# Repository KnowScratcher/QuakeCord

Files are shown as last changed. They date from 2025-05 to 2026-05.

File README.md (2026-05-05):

> [!WARNING]
> The server part will be in a different repo, the code here is outdated. See [QuakeCord-server](https://github.com/KnowScratcher/QuakeCord-server).

# QuakeCord
<p align="center">
Whenever an earthquake strikes, you should know what's going on.
</p>

<div align="center">
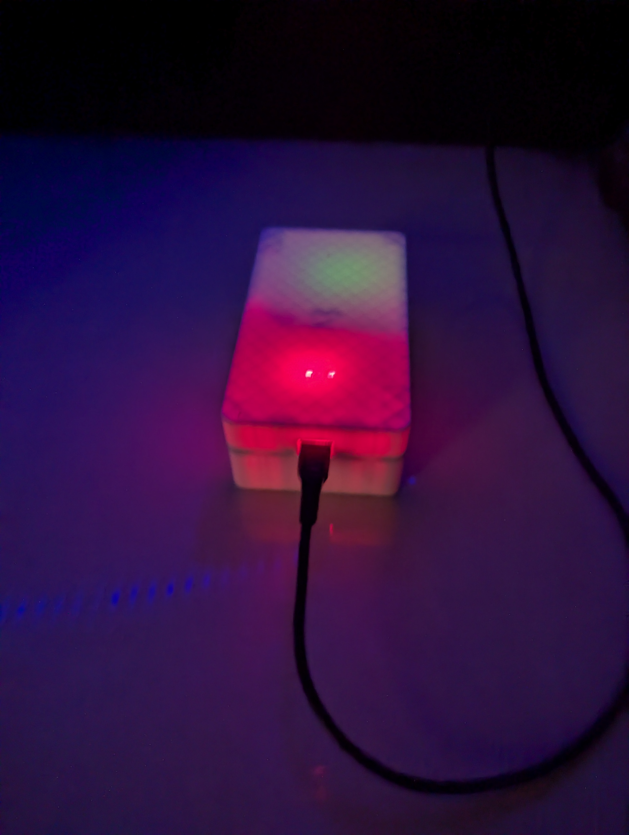
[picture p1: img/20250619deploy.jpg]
    <br>
    certificate
</div>

# BOM
Because I live in Taiwan, so I'll add a TWD column.

| Item | Amount | Price(USD) | Total(USD) | Total(TWD) |
| --- | --- | --- | --- | --- |
| ESP32 dev module | 1 | 5.34 | 5.34 | 160 |
| MPU6050 (soldered) | 1 | 4.33 | 4.33 | 130 |
| Case (3D print) | 1 | 0.91 | 0.91 | 27 |
| Jump wire (pin - socket)  | 5 | 0.19 | 0.19 | 6 |
| Breadboard mini (45x35mm) | 1 | 0.17 | 0.17 | 5 |
| Total | | | 10.75 | 328 |

> [!NOTE] 
> - If you'd like to find a case for the project, go ahead.
> - A 3D printed case will be a cheaper option. (Assuming PLA costs $13.4/KG)

# Journal
The journal is in [JOURNAL.md](JOURNAL.md)

A brief summery of the journal:

## How it all started
I've been wanting to make something useful and about earthquake since I lived in a place with lots of earthquake. Just this simple reason.

## What will it do?
- detect earthquake
- record the acceleration data for further research
- send notification to discord
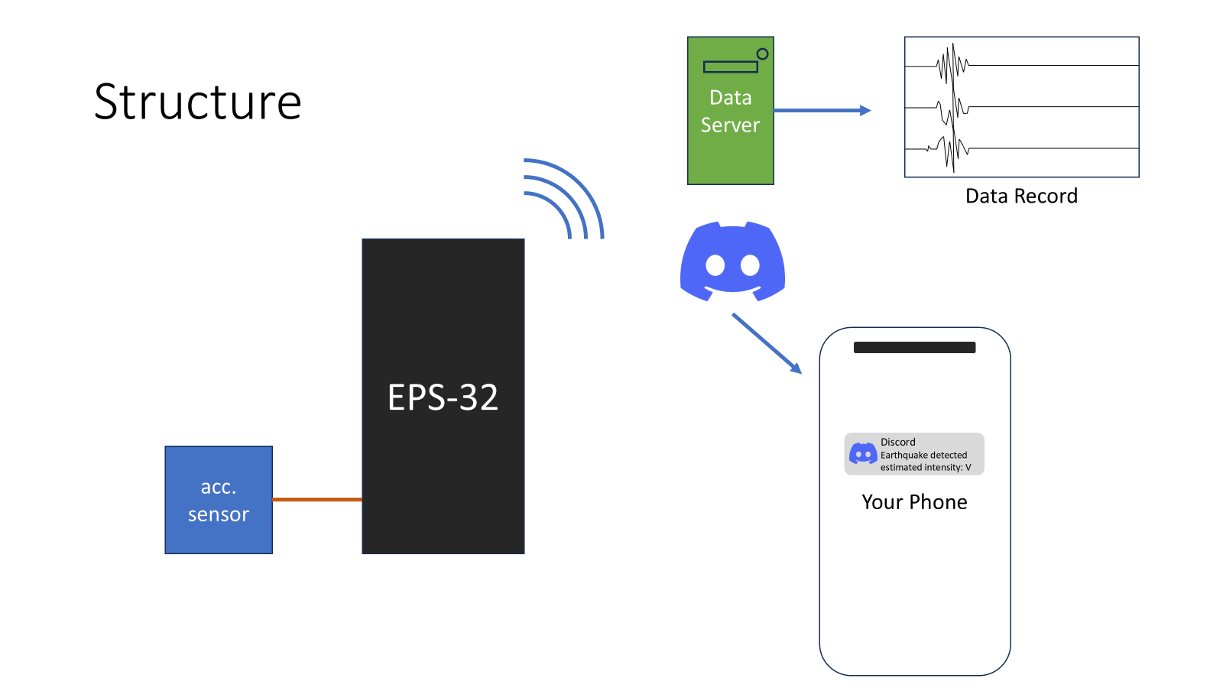
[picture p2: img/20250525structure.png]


# How to make one
1. Head over to [src > print](https://github.com/KnowScratcher/QuakeCord/tree/main/src/print) and download the file you need.

   `QuakeCord_case.3mf`: the whole case including base and cap. (if you choose this, you don't have to download the others.)
   
   `QuakeCord_case_case.3mf`: the base of the case.
   
   `QuakeCord_case_cap.3mf`: the cap of the case.

   Also stl file is provided.

   `QuakeCord_case.stl`: the whole case including base and cap. (if you choose this, you don't have to download the others.)
   
   `QuakeCord_case_case.stl`: the base of the case.
   
   `QuakeCord_case_cap.stl`: the cap of the case.
   
2. Assemble the parts as follows:
   Detail in [wiki](https://github.com/KnowScratcher/QuakeCord/wiki).
   1. glue or foam tape the breadboard onto the case. If 3d printed, there should be an area marked the same size as the breadboard.
   2. plug your MPU6050 onto the breadboard. Note that the pins should align vertically, that is, along the direction which has more holes.
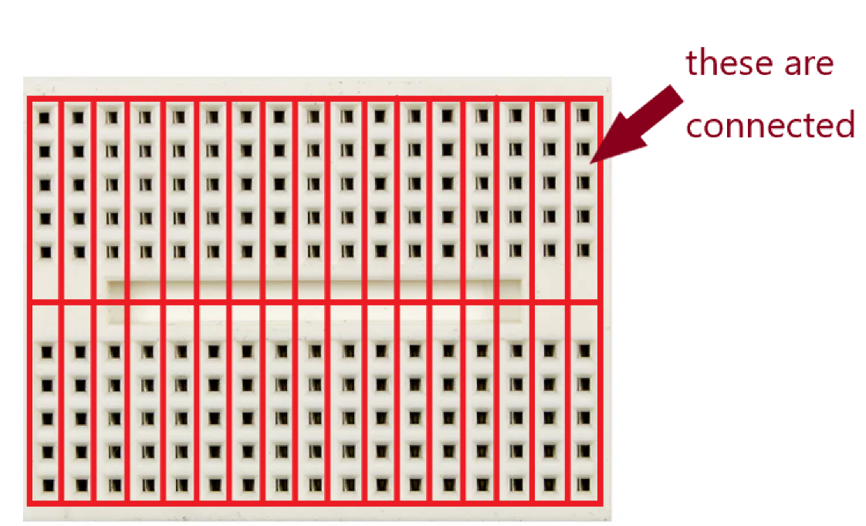
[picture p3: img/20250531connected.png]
what is connected on a breadboard
      
      
      (breadboard image from [arduino store](https://store.arduino.cc/products/mini-breadboard-white))
      
   3. connect the jump wires from ESP32 to the breadboard as follows:
      | ESP32 pin | MPU6050 pin (breadboard) |
      | --------- | ------------------------ |
      | 3v3       | VCC                      |
      | GND       | GND                      |
      | D22       | SCL                      |
      | D21       | SDA                      |
      | D15*      | INT*                     |
      
> [!NOTE]
> An unknown error might appear when you connect the `INT` to the ESP32.
>
> If your QuakeCord suddenly stops working about 30 minutes after you plug in, remove the connection of this pin.
   5. find the script at [not available](about:blank) and edit the setting. (Detail in [wiki](https://github.com/KnowScratcher/QuakeCord/wiki).)
   6. upload the script to your ESP32.
   7. Plug the device somewhere you won't be often and you're good!!!
  
# Software
CAD: PowerPoint, FreeCAD

Programming: VS code, Arduino IDE

Image editing: Paint 3D

# Licensing

This project comprises both hardware designs and software components, each licensed separately to ensure clarity and appropriate reciprocity.

## Long story short
certificate

## Hardware Designs (3D Models, Wiring Diagrams, etc.)

All hardware design files, including but not limited to 3D models, PCB layouts, and schematic diagrams, excluding the ESP32 board, are licensed under the **CERN Open Hardware Licence Version 2 - Strongly Reciprocal (CERN-OHL-S-2.0)**.
You can find the full text of this license in [LICENSE_HARDWARE](LICENSE_HARDWARE).

## Software (Data Server, ESP32 Firmware, etc.)

All software components, including but not limited to the data server application and ESP32 firmware, are licensed under the **GNU Affero General Public License Version 3.0 or later (AGPL-3.0-or-later)**.
You can find the full text of this license in [LICENSE_SOFTWARE](LICENSE_SOFTWARE).

## Documentation

All documentations, including but not limited to the README.md and wiki pages, are licensed under the **CC-BY-SA-4.0**.
You can find the full text of this license in [LICENSE_DOCUMENTATION](LICENSE_DOCUMENTATION)

# Contribute
## Files
### Step Files
step files are available at [src > step](https://github.com/KnowScratcher/QuakeCord/tree/main/src/step)

`QuakeCord_case.step`: All parts together.

`QuakeCord_case_case.step`: only the base.

`QuakeCord_case_cap.step`: only the cap.

Please update all three CADs to your design.
### FreeCAD File
find the `.FCStd` at [src](https://github.com/KnowScratcher/QuakeCord/tree/main/src)

`QuakeCord.FCStd`: the model.

`QuakeCord_case.FCStd`: the actual case. (both base and cap)

## PR
Please describe what exactly you have changed, I will review the PRs once in a while, be patient!

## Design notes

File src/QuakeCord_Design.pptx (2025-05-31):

## QuakeCord Design

The design file

## Structure

Data Server

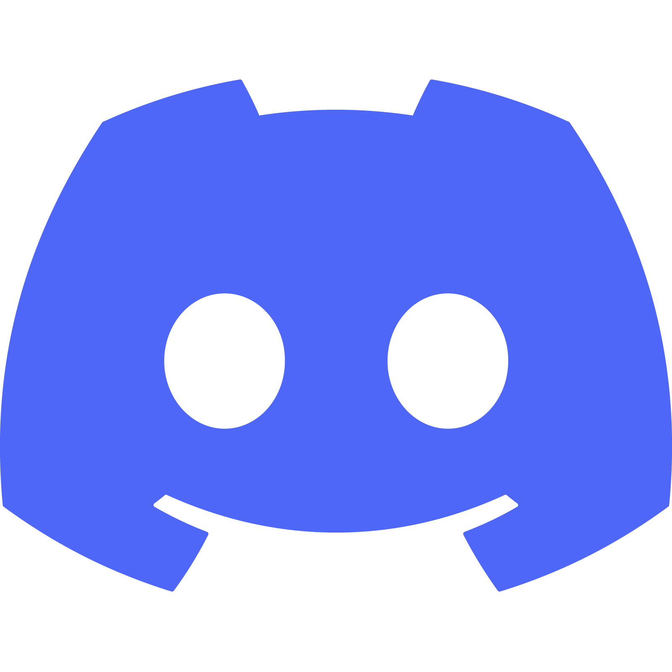
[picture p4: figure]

Data Record

此相片 (http://funclubfrp.wikidot.com/faq) (作者: 未知的作者) 已透過 CC BY-SA (https://creativecommons.org/licenses/by-sa/3.0/) 授權

此相片 (http://funclubfrp.wikidot.com/faq) (作者: 未知的作者) 已透過 CC BY-SA (https://creativecommons.org/licenses/by-sa/3.0/) 授權

EPS-32

Your Phone

Discord

Earthquake detected
estimated intensity: V

acc. sensor

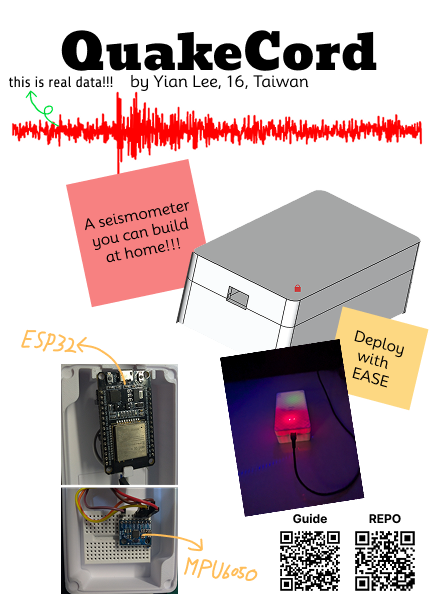
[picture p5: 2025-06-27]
img/quakecord.png

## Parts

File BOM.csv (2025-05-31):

Item | Amount | Price(USD) | Total(USD)
ESP32 dev module | 1 | 5.34 | 5.34
MPU6050 (soldered) | 1 | 10.02 | 10.02
Case (3D print) | 1 | 0.91 | 0.91
Jump wire (pin - socket) | 5 | 0.19 | 0.19
Breadboard mini (45x35mm) | 1 | 0.17 | 0.17
Total |  |  | 16.63

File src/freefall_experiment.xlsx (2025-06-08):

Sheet: raw
8154
7945
7967
7483
8041
8037
7858
8353
8133
7549
7993
7870
7804
7990
7921
7932
8069
8122
8219
8179
8098
7945
8196
8182
8303
8180
8079
8143
8109
8004

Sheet: Plot
id | value | y | id | Average | id | y
experiment | 8154 | 0.5 |  |  |  | 0
experiment | 7945 | 0.5 | experiment | 8028.6 | experiment | 0.5
experiment | 7967 | 0.5 | 0 |  |  | 1
experiment | 7483 | 0.5
experiment | 8041 | 0.5
experiment | 8037 | 0.5
experiment | 7858 | 0.5
experiment | 8353 | 0.5
experiment | 8133 | 0.5
experiment | 7549 | 0.5
experiment | 7993 | 0.5
experiment | 7870 | 0.5
experiment | 7804 | 0.5
experiment | 7990 | 0.5
experiment | 7921 | 0.5
experiment | 7932 | 0.5
experiment | 8069 | 0.5
experiment | 8122 | 0.5
experiment | 8219 | 0.5
experiment | 8179 | 0.5
experiment | 8098 | 0.5
experiment | 7945 | 0.5
experiment | 8196 | 0.5
experiment | 8182 | 0.5
experiment | 8303 | 0.5
experiment | 8180 | 0.5
experiment | 8079 | 0.5
experiment | 8143 | 0.5
experiment | 8109 | 0.5
experiment | 8004 | 0.5
Source: Northwind Traders.

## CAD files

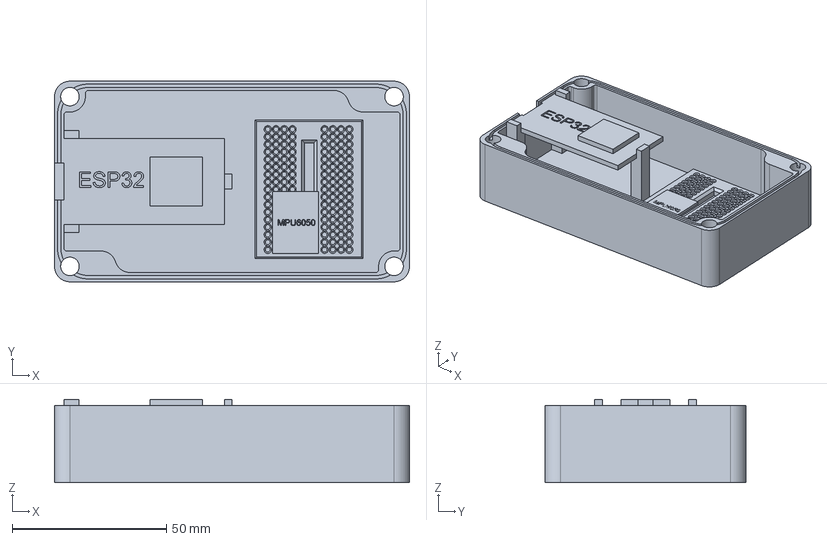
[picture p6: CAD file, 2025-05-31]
src/QuakeCord.FCStd
115.0 x 65.0 x 27.0 mm

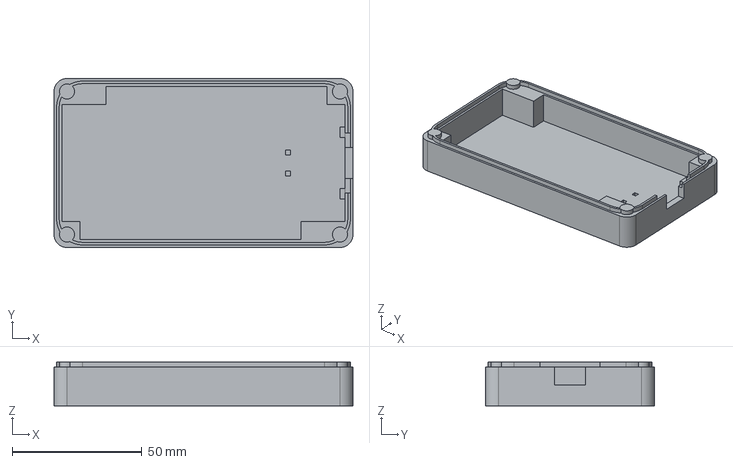
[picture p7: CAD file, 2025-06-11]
src/step/QuakeCord_case-cap.step
115.0 x 65.0 x 16.9 mm

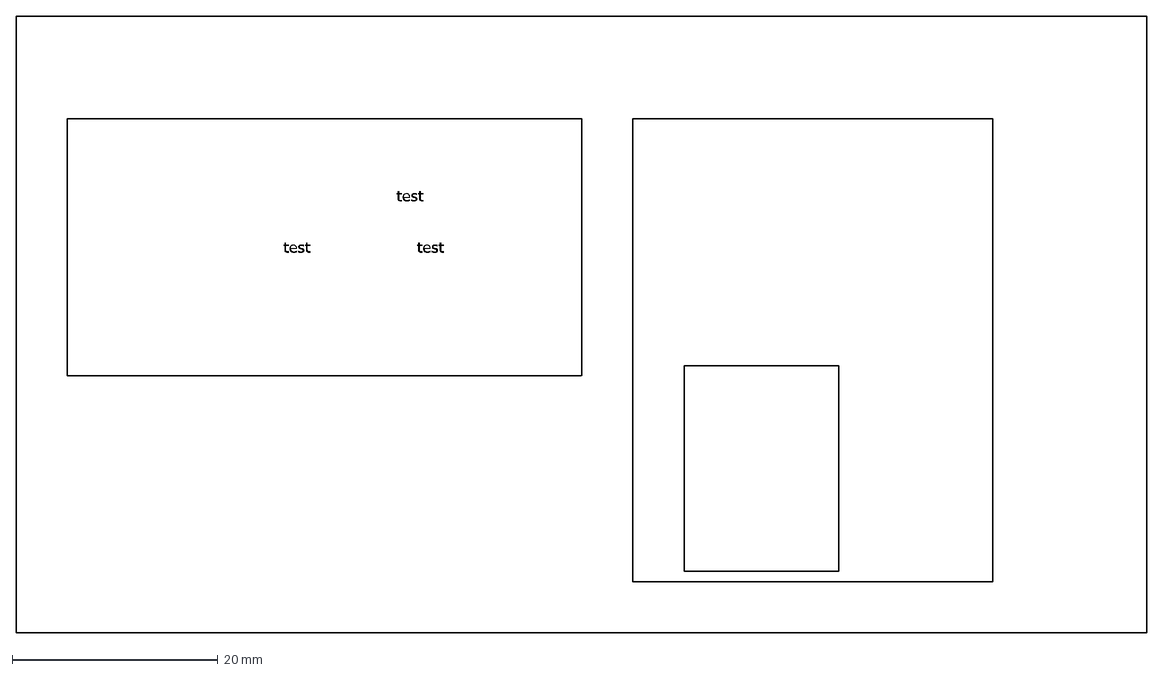
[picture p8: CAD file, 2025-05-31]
src/QuakeCord_Design.dxf
test

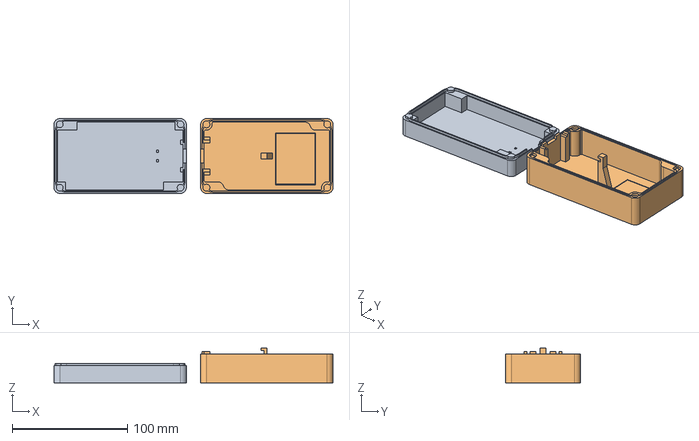
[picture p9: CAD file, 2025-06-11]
src/step/QuakeCord_case.step
242.5 x 65.0 x 30.0 mm
cap
case

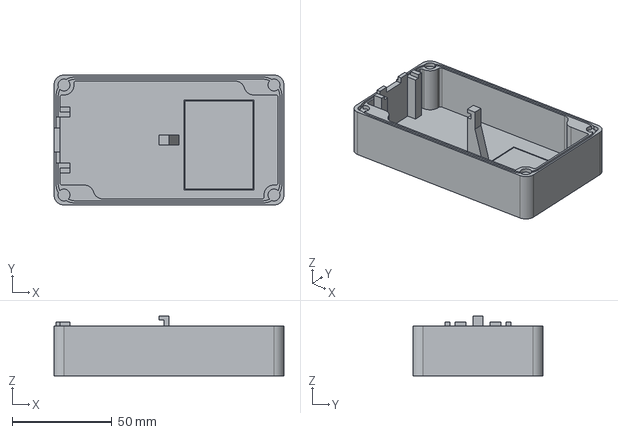
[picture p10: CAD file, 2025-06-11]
src/step/QuakeCord_case-case.step
115.0 x 65.0 x 30.0 mm

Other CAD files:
src/QuakeCord_case.FCStd
src/print/QuakeCord_case-cap.3mf
src/print/QuakeCord_case-cap.stl
src/print/QuakeCord_case-case.3mf
src/print/QuakeCord_case-case.stl
src/print/QuakeCord_case.3mf
src/print/QuakeCord_case.stl

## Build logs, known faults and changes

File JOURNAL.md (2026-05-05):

---
title: "QuakeCord"
author: "Know Scratcher"
description: "An earthquake sensor that connects with discord."
created_at: "2025-05-25"
---

# May 25th: Research and Design + Build a Prototype.

I finally decided to start this project. I've been wanting to make something useful and about earthquake since I lived in a place with lots of earthquake.

The function I planned to have are:
- detect earthquake
- record the acceleration data for further research
- send notification to discord

Here's a quick picture explaining this:

structure

So the things I would need:
- EPS32 (controlling the sensor)
- An accelerometer (of course, for obtaining data)
- A case (for dust protection)
- A data server (for collecting data)

I'll use an ESP-32 dev module to control the hardware because I'm more familiar with it.

Next, I'll need an acceleration sensor. I ask Gemini for suggestion on the sensors, but it seemed like ADXL345 and MPU6050, which I already have, are the most sensitive sensor I can find.

So I read through the data sheet of the [ADXL345](https://www.analog.com/media/en/technical-documentation/data-sheets/adxl345.pdf) and [MPU6050](https://invensense.tdk.com/wp-content/uploads/2015/02/MPU-6000-Datasheet1.pdf).

After all, I decide to use MPU6050 because its extensibility. It has an accelerometer and a gyroscope, which might make it more possible for something more complicated than only an accelerometer.

I use a breadboard to hold my sensor, which it flat enough at the bottom to make the sensor stable, and also I glued a little piece of plastic that somehow just fit the height of the sensor to hold the sensor's other end. 

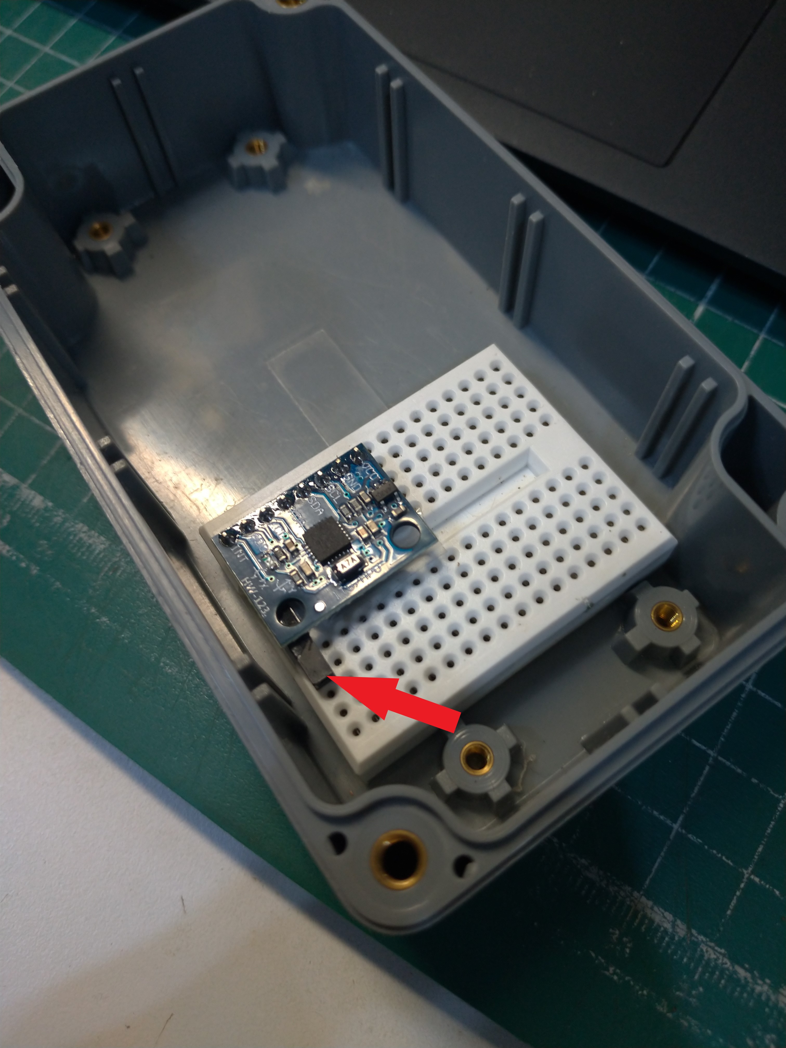
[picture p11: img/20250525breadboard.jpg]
breadboard


Then, I found a library for MPU6050 and spend about one hour trying to understand the example program.

**Total time spent: 4h**

# May 31th: Draw design with FreeCAD.

Basically what I did today is draw the case for the controller and sensor.

I use an existing box as a reference and slightly change the design a little bit to fit.

I got a little pissed when freeCAD not responding every time I was finishing a step.

Because I'm the first time using this software, so I feel a little hard to control everything, but after all the pissing and agony, I finally got something that can be showed.

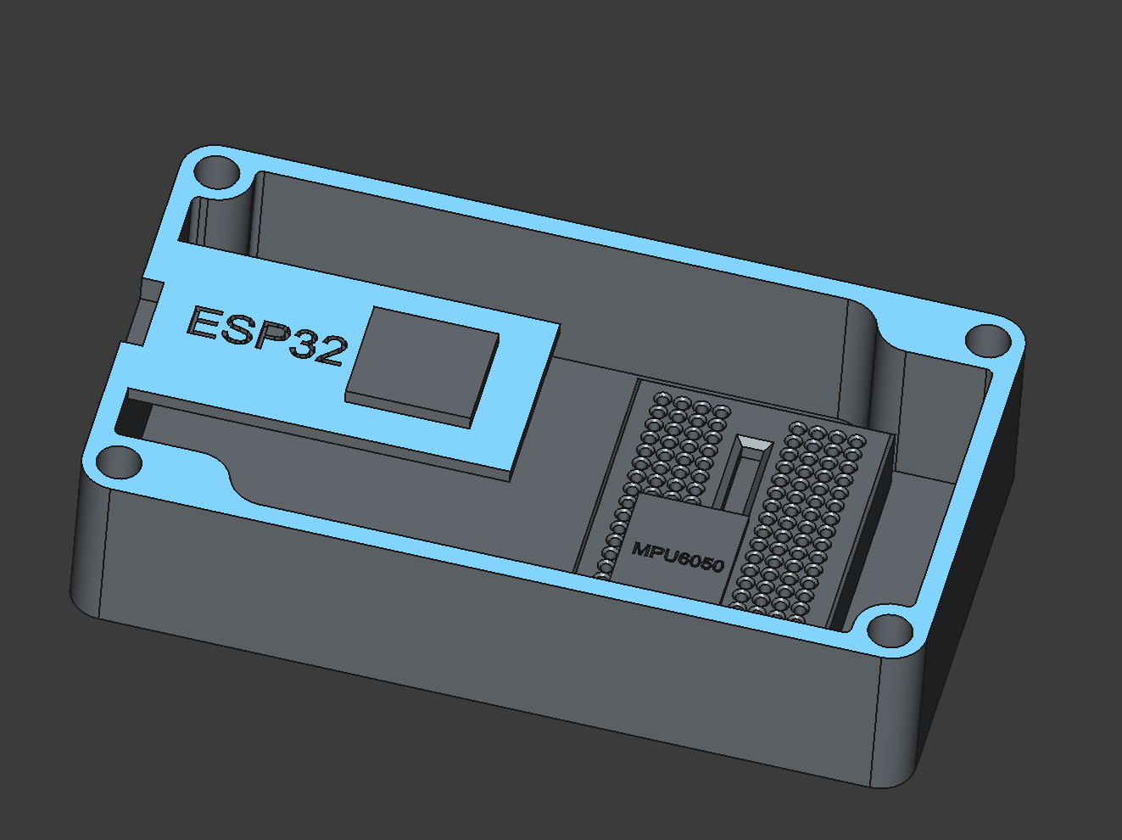
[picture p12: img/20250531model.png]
model


Then I extract the case from the overall design to make it 3D printable. 

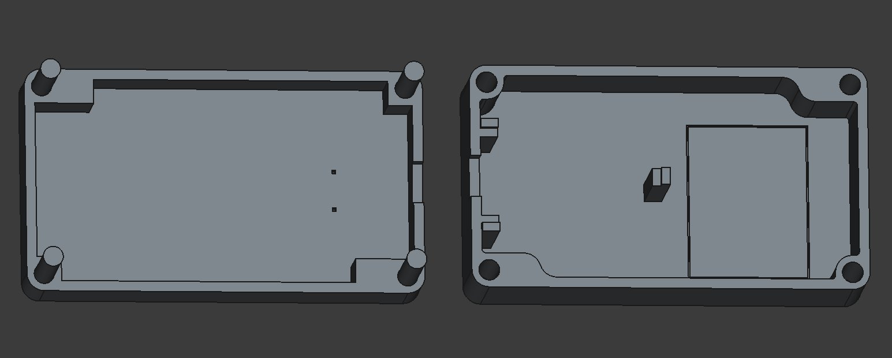
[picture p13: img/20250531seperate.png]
separate


Quickly I realized how stupid I am. I just forgot to add a hole for the power line.

So I quickly drill a hole on the model, then, even more stupid, I forgot that the board needs to be placed facing up to let the user be able to read the builtin lights. I almost cry out, like I spent 3 hour just for this thing to have a shape, and now there's lots and lots of problem. 

After fixing that, the model looks fine, so I export it and put it into Cura to slice it for 3D print.

A very huge problem popped out. Though I am going to use my school's 3D printer, most of the printers have a time limit of around 2hr, anything above that might got removed by the teacher. So I gotta go find my teacher and try my best to persuade him to let me print this part that takes 6 hr to print (9 hr when all are printed at the same time).

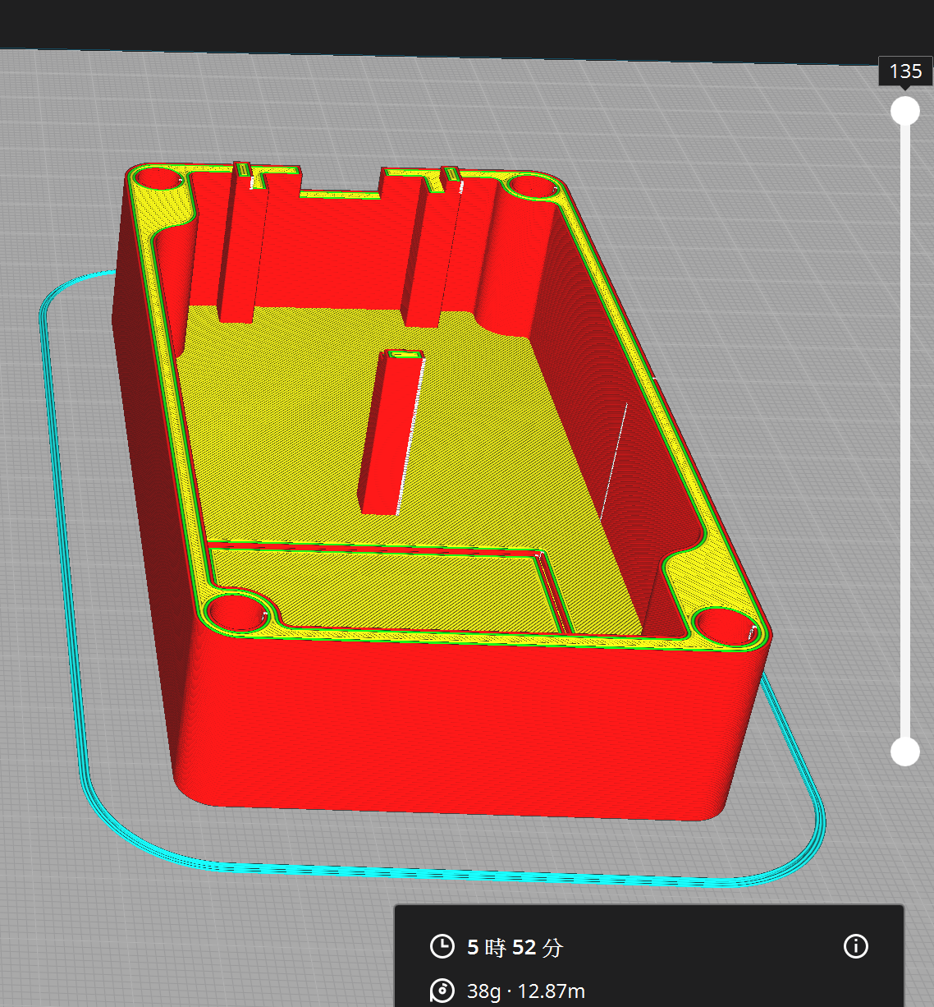
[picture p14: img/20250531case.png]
case print time


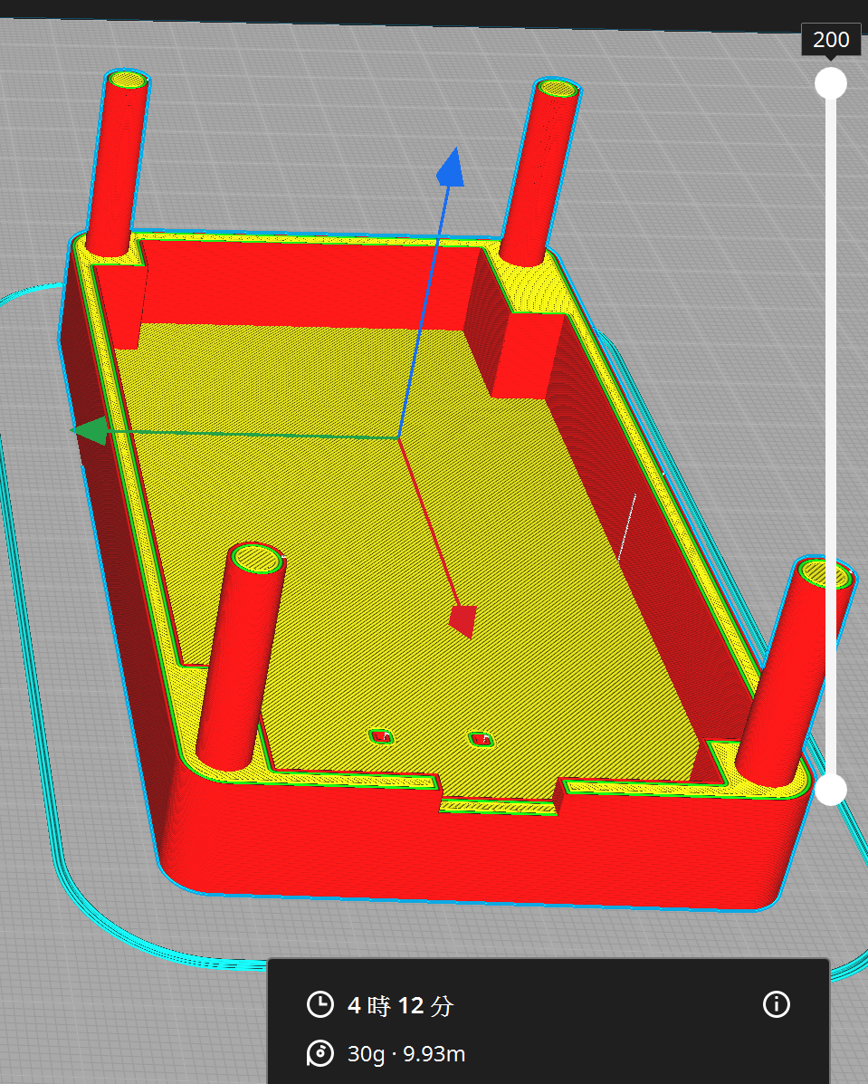
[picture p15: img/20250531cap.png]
cap print time


(時=hour, 分=minute)

Well, at least I worked something out. Just... have to tell my teacher... Hope this works.

I worked a little bit more at night to fix the closing gap. Now it look something like this

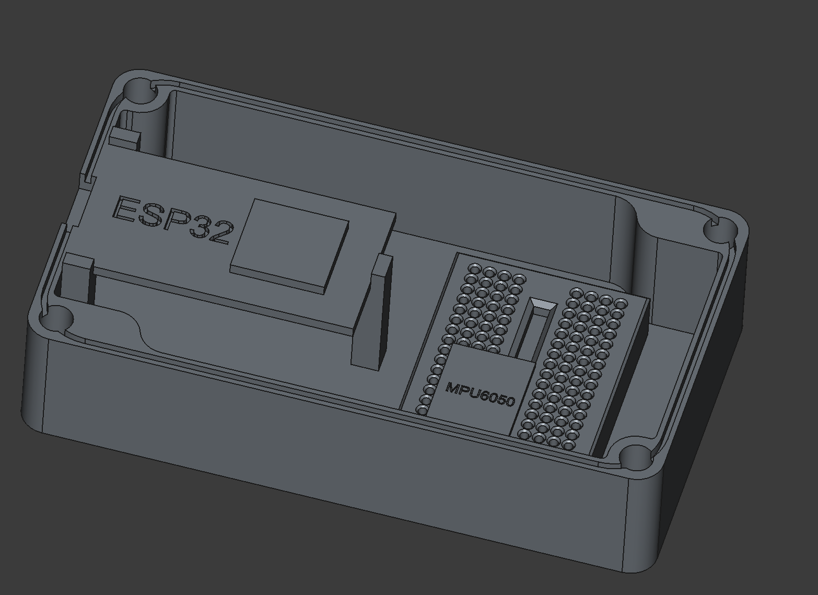
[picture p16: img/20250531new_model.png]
new model


**Total time spent: 8h**

# June 2nd: Try printing the model and fixing it.

Today, I ask my teacher to print the case out for me. Well, you know, teacher... he just bring out his super fast 3d printer and get everything done under 2 hrs.

The led holes are too small, so I change it to be bigger in the CAD and also drill the printed model to make things look nice. In fact the alignment is incredible.

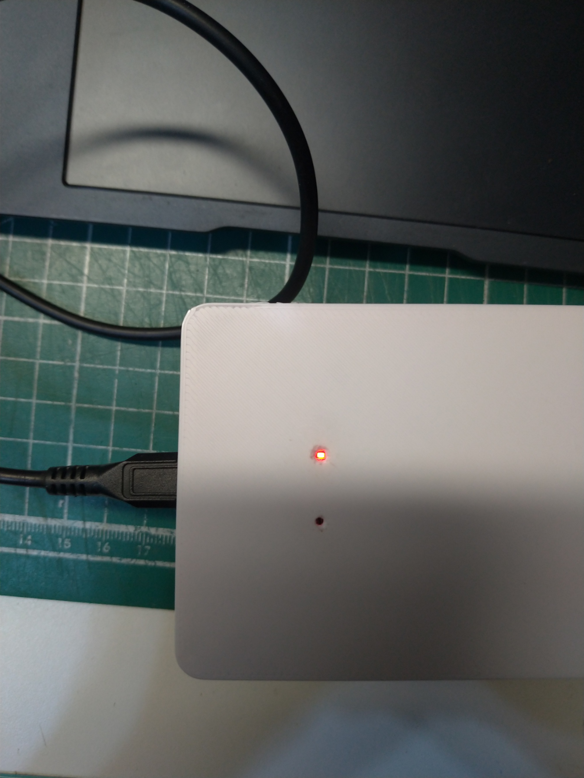
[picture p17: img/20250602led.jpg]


The board holder worked as expected, but a little bit tight, so I fixed it again.

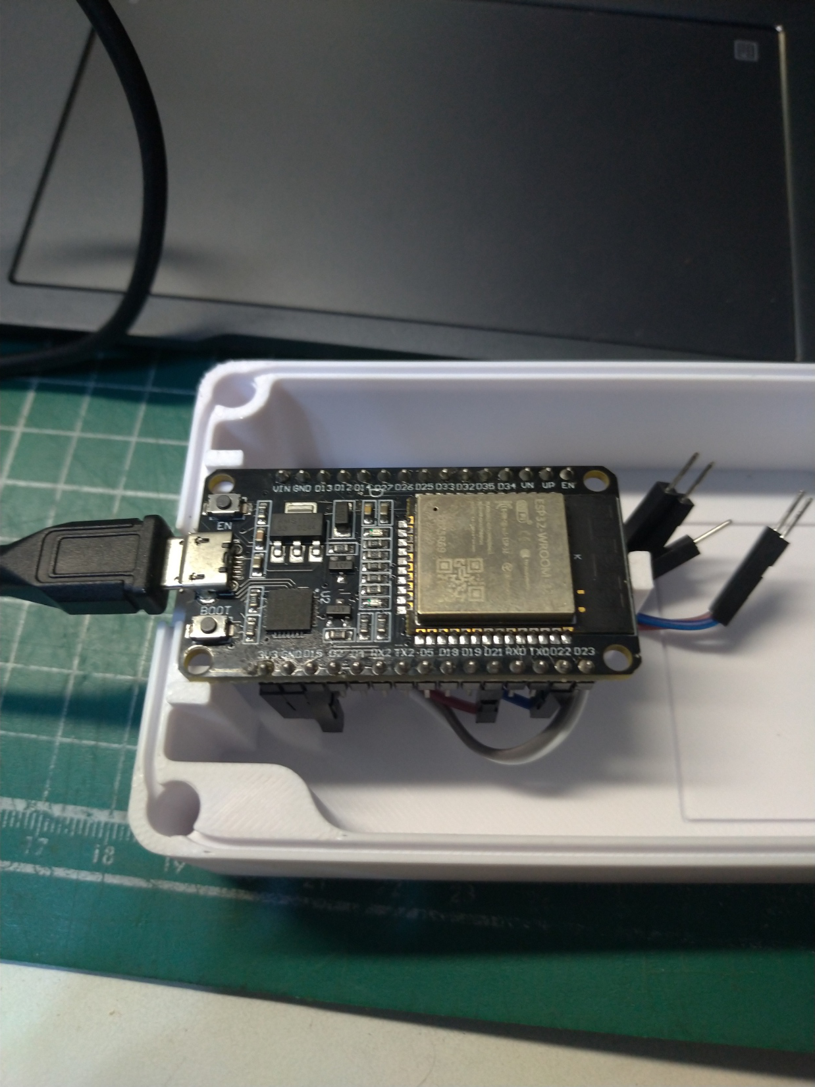
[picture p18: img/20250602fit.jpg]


After I got the case, I soon found that there's two main problem:

First is that when I touch the four "feet" of the cap, it instantly break apart, which means it's not a good solution to use the structure. But it surprised me another time by being able to fit and close just using the little "trench" I dug around the edge.

Second is that the hole for power doesn't fit the power plug at all,

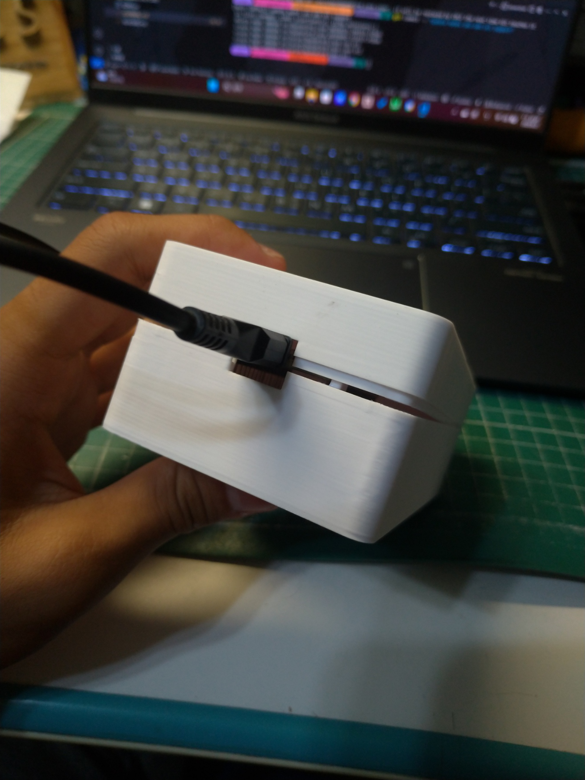
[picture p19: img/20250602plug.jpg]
the hole doesn't fit


so I just fix that simply going back suffering in the CAD.

Also, I added a little bump to hold the ESP32 just to make sure it doesn't slip like this

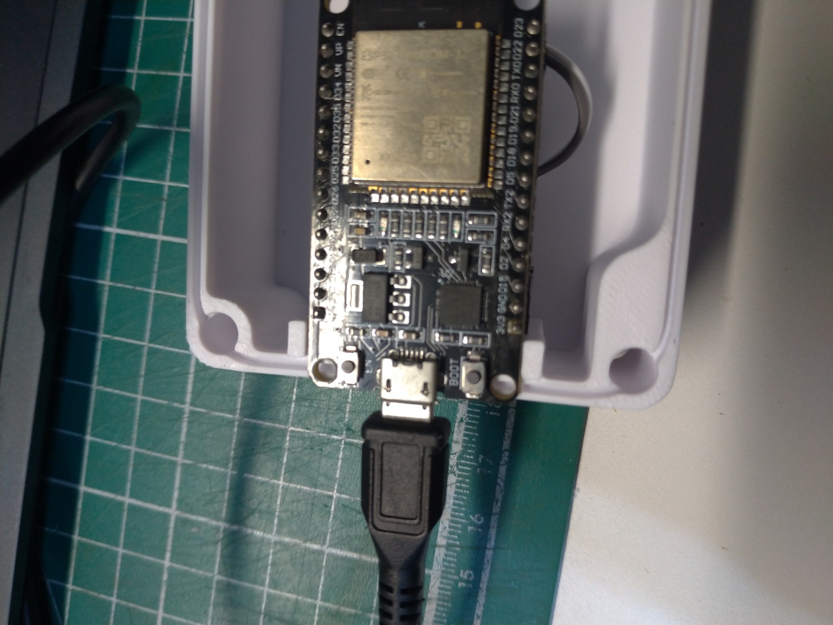
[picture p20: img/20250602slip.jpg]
board slip when unplugging


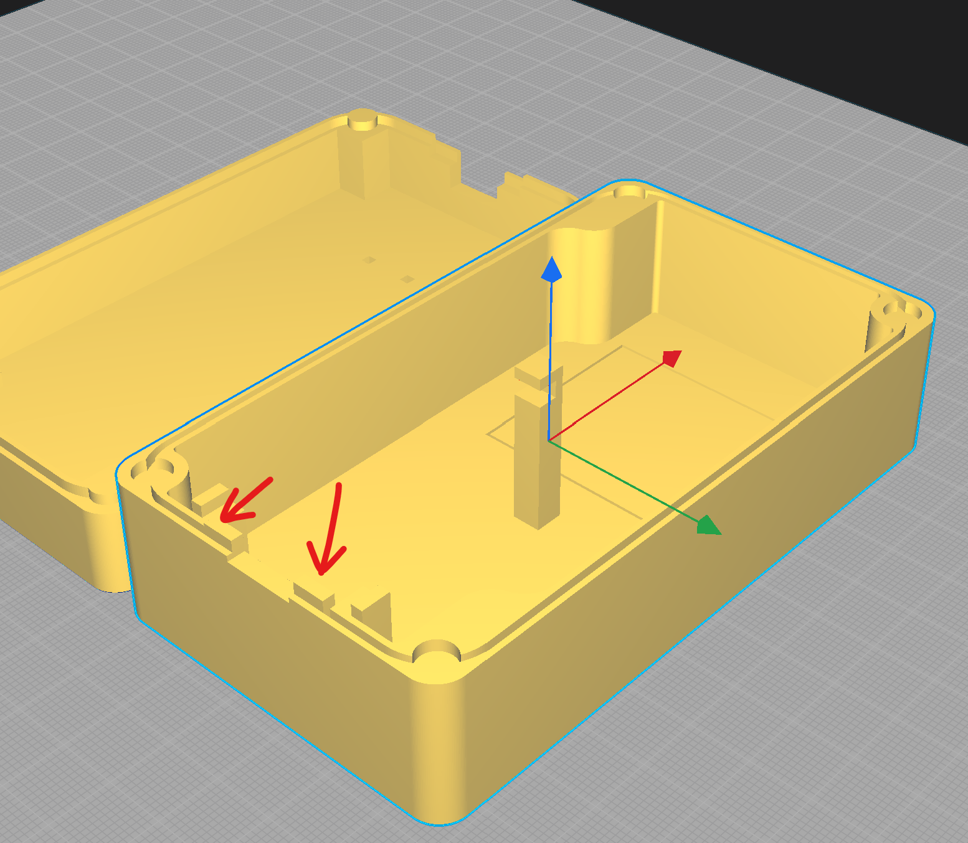
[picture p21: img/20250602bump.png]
bump


also I worked on the [MagFire](https://github.com/KnowScratcher/MagFire) project today, and you should definitely check it out.

**Total time spent: 2h**

# June 3rd: Fix the model once again.

So I some how figured out that this support here might not be strong enough to withstand the force installing of push into it, so I add made the support thicker at the bottom to prevent it from breaking.

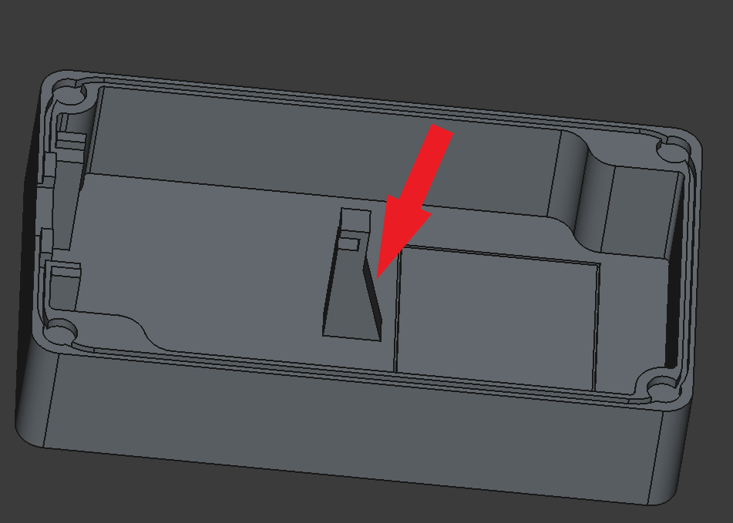
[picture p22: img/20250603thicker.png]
I made the support thicker


**Total time spent: 2h**

# June 4th: Print the second model.

My teacher seems supportive and help me print another version of the model, this time, the power line fit smoothly. 

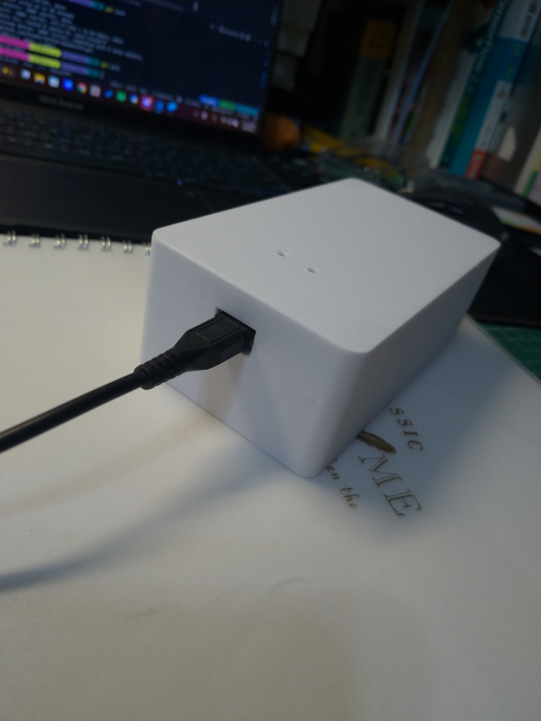
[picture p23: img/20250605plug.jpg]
the power line fit smoothly


However, the board holder is a little bit too loose, so I changed the CAD once again.

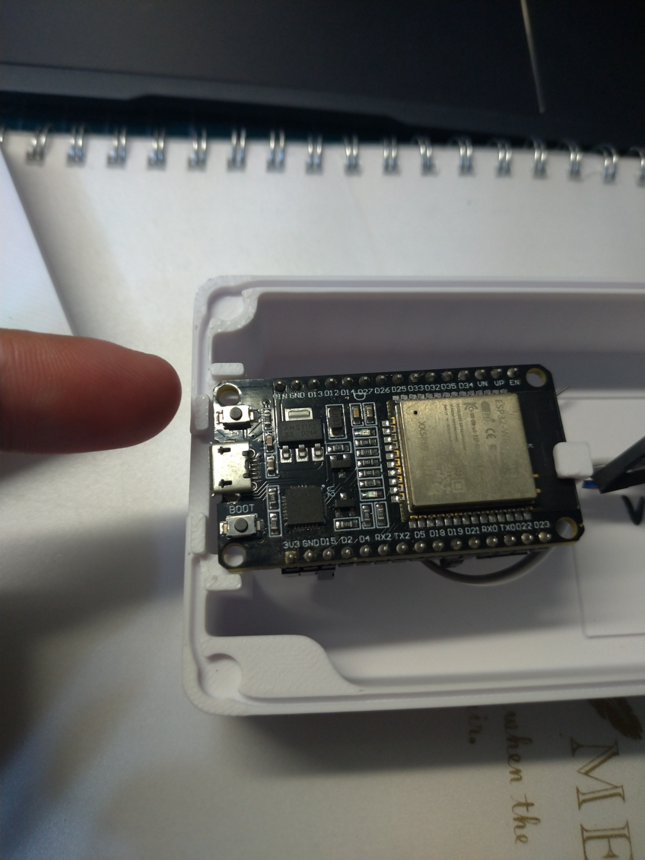
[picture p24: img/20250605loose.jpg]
the board holder is a little bit too loose


I was thinking to add a little hand at the edge of the cap the hold the board so that it don't fly up and make it impossible to plug the line in once it's unplugged. 

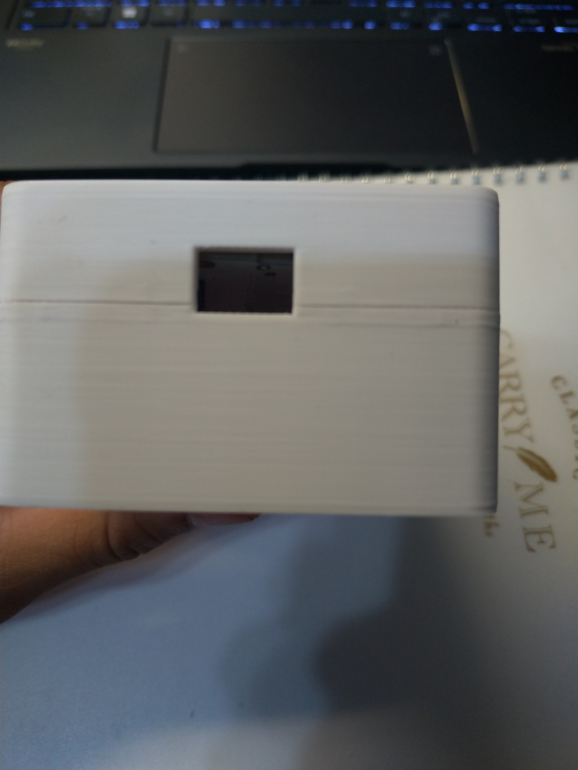
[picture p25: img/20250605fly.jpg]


Though my teacher suggested me to just put some foam around the board, but to me, it doesn't feel good to tell a random person who want to make this to randomly put some foam in some random places and make it look like a thing taken out from the landfill, so I just decided to fix the CAD and print it again.

**Total time spent: 3h**

# June 6th: Fix the issue of the second model.

So I added some parts to hold the board better 

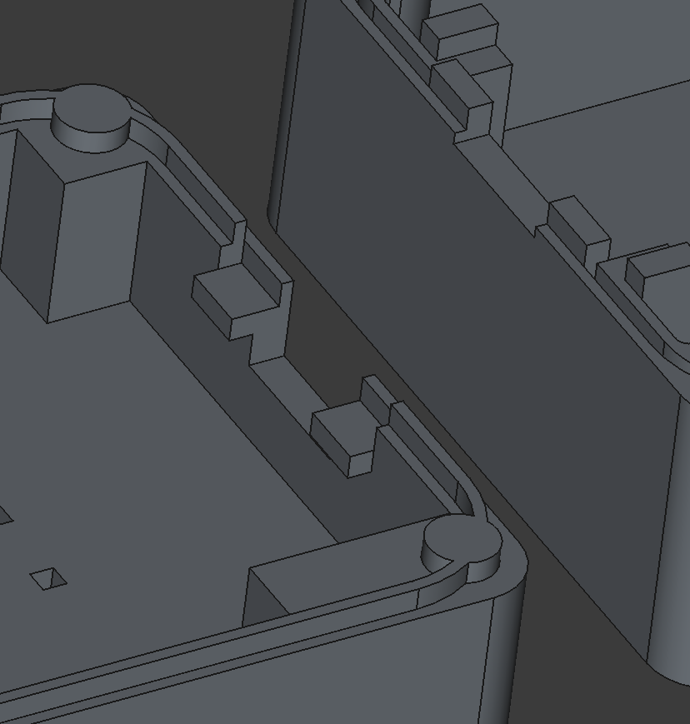
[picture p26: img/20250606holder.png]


and hope it works.

**Total time spent: 1h**

# June 8th: Working on the firmware.

So Today I wrote the firmware for the ESP32.

I first started with the example script of the MPU6050 library. Then I rearrange and separate it into multiple functions that setup and read the data from the sensor.

While I was taking my break, I think of the possibility of running multiple thread on the ESP32, so I looked up online, and I found this [blog (Traditional Chinese)](https://youyouyou.pixnet.net/blog/post/120275992). I read through and found it very interesting so I decided to implement it.

When I test the code, it worked just as I expected. But it was not done yet, still some small bug to fix and I have to link it to discord.

Another thing is that I fell into an issue that the data I'm getting is not gal (a kind of acceleration unit) rather a unknown unit. So I did a little free-fall experiment to the sensor and get its data. The experiment data are in [freefall_experiment.xlsx](https://github.com/KnowScratcher/QuakeCord/tree/main/src/freefall_experiment.xlsx)

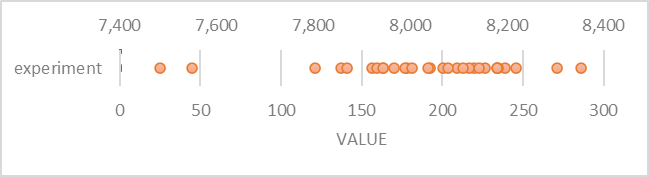
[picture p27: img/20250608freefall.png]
free fall experiment result


<video controls src="https://raw.githubusercontent.com/KnowScratcher/QuakeCord/refs/heads/main/video/20250608freefall.mp4" height="400" alt="free fall experiment result2">

<video controls src="https://raw.githubusercontent.com/KnowScratcher/QuakeCord/refs/heads/main/video/20250608data.mp4" height="400" alt="free fall experiment result3">

and average the result and calculate the ratio of the value get to gal, in which I found out that the data sheet is absolutely wrong. (they say 2048:960 but actually 8028.6:980, probably because I use DMP...)

About an hour later, I finished the webhook for discord. Now the last thing is to let it decide whether it's an earthquake. (Well, I just gonna suffer when I see this)

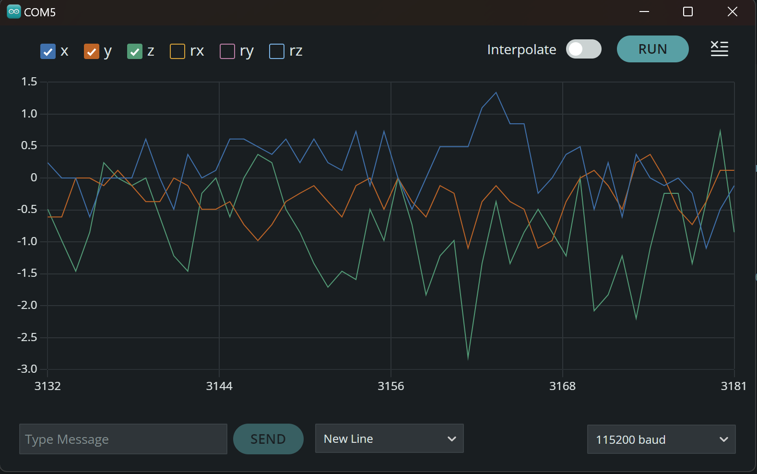
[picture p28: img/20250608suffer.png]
suffer


I also got my hand on to the data server. I wrote it in python, which is more familiar to me then arduino. So I quickly finished the server. Now it should be able to store the data sent from the sensor and send signal to restart sensor if it receives unregistered data to make it register again (well, also for calibration purpose).

Ok, I've finished all the part. That was really tired to write code for such a long hour. 

<video controls src="https://raw.githubusercontent.com/KnowScratcher/QuakeCord/refs/heads/main/video/20250608test.mp4" height="400" alt="free fall experiment result3">

Next week I might just print the new model out and assemble it and finish the rest of the job, and hopefully mark a end to this project.
**Total time spent: 6h**

# June 9th: Write tutorial for building the project

I finished the tutorial of making a QuakeCord from step 1 to step 7. It was just continuous writing, and kinda boring I would say.

**Total time spent: 3h**

# June 10th: Still writing the tutorial and update the model

So I updated the model once again. I add some support onto the cap.

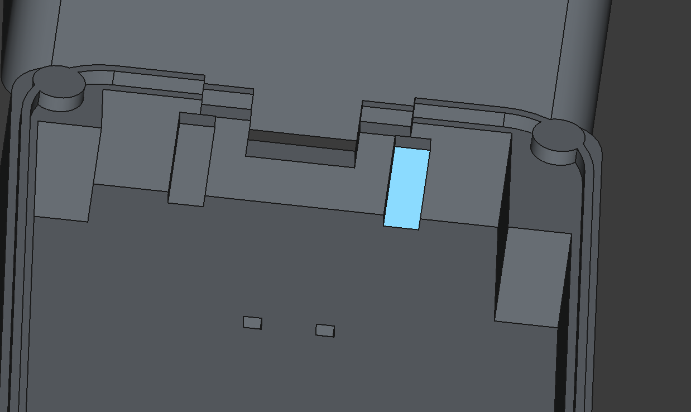
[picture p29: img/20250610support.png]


**Total time spent: 1h**

# June 14th: Assemble the parts.

I officially assembled all the parts together and deployed the project. I put the sensor in a vacant room where no one will go and set up my data server, now it's working and collecting data.

also, I found out an issue with the INT pin so I disconnected it so it could work as expected.

suffer

**Total time spent: 1h**

# June 14th: Take picture and finish magazine page.

Today I finished the magazine page for this project and also took picture for it. 

**Total time spent: 1h**

# June 26th: Got OSHWA certificate.

I got the open source certificate from OSHWA. That was really an encouragement for me to keep doing this.

Here, take a look at this beautiful thing

certificate

Also, the PCB finally arrived.

**Total time spent: 0h**

# July 1st: Update server to allow live data visualization.
I rewrite the server program to allow me to access the data right after it's sent to the server.

I made a web ui and add some charts to show the streamed the data from websocket.

**Total time spent: 3h**

# July 2nd: Finish up the update.

So I finish up the update of the streaming page and push to github.

**Total time spent: 1h**

# August 19th: edit image on readme.
**Total time spent: 0h**

# December 27th: Fix Server issue, add extra Debugging code

Well, the new firmware is still in alpha test, not available right now.
**Total time spent: 3h**

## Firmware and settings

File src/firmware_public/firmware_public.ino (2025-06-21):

#include "I2Cdev.h"
#include "MPU6050_6Axis_MotionApps20.h"
#include <ArduinoJson.h>
#include <HTTPClient.h>
#include <WiFi.h>
#include <math.h>

/*---Settings---*/
// WIFI
const char *ssid = ""; // Enter SSID
const char *password = "";   // Enter Password

// Data Server
const bool enableServer = false;  // Enable server mode, send data to server
const char *dataServer = "";     // the server data url, with "http://" at the beginning
const char *registerServer = ""; // the server register url, with "http://" at the beginning
const char *StationID = "";      // a unique id for the server to recognize your station

// Discord
const bool enableDiscord = true;                                                                                                                   // Enable discord mode, send notification to discord
const char *webhook = ""; // discord webhook url

// intensity type setting

/* uncomment the one you want to use and comment the others*/

#define MMI; // Global (Mercalli intensity scale)
// #define CWASIS ; // Taiwan (Taiwan seismic intensity scale)
// #define JMA; // Japan (Japan Meteorological Agency seismic intensity scale)
// #define CSIS; // China (China seismic intensity scale)

/* note that PEIS (PHIVOLCS earthquake intensity scale) is not supported*/

// Constant Setting (do not touch if you don't know what you're doing)
const float dataRatio = 980.0 / 8028.6; // the ratio of data:gal, 8028.6 is the experiment result
const float threshold = 3.5;            // the threshold of earthquake or noise

/*---End Settings---*/

MPU6050 mpu;

#define LED_BUILTIN 2

int const INTERRUPT_PIN = 15; // Define the interruption #0 pin
bool blinkState;

/*---MPU6050 Control/Status Variables---*/
bool DMPReady = false;  // Set true if DMP init was successful
uint8_t MPUIntStatus;   // Holds actual interrupt status byte from MPU
uint8_t devStatus;      // Return status after each device operation (0 = success, !0 = error)
uint16_t packetSize;    // Expected DMP packet size (default is 42 bytes)
uint8_t FIFOBuffer[64]; // FIFO storage buffer

/*---Calibrate---*/
const int usDelay = 3150; // Delay in ms to hold the sampling at 200Hz
const int NFast = 1000;   // Number of quick readings for averaging, the higher the better
const int NSlow = 10000;  // Number of slow readings for averaging, the higher the better
const int LinesBetweenHeaders = 5;

const int iAx = 0;
const int iAy = 1;
const int iAz = 2;
const int iGx = 3;
const int iGy = 4;
const int iGz = 5;

int LowValue[6];
int HighValue[6];
int Smoothed[6];
int LowOffset[6];
int HighOffset[6];
int Target[6];
int LinesOut;
int N;
int i;
// float zDatas[1000];
// float zOffset;

int16_t ax, ay, az;
int lax[4], lay[4], laz[4];
int mainCount;

/*---Orientation/Motion Variables---*/
Quaternion q;        // [w, x, y, z]         Quaternion container
VectorInt16 aa;      // [x, y, z]            Accel sensor measurements
VectorInt16 gy;      // [x, y, z]            Gyro sensor measurements
VectorInt16 aaReal;  // [x, y, z]            Gravity-free accel sensor measurements
VectorInt16 aaWorld; // [x, y, z]            World-frame accel sensor measurements
VectorFloat gravity; // [x, y, z]            Gravity vector

/*---Controling variable---*/
long long worldtime = 0;
unsigned long baseSystemTime = 0;
int t = 0;
bool sendSignal = false;
bool discordSignal = false;
bool discordLock = false;
bool reportSignal = false;
int interest = 0;
int errorLevel = 0;
float pga = 0;
float start_x = 0;
float start_y = 0;

unsigned int baseTime = 0;
String mode = "unknown";
JsonDocument sendData;
JsonDocument buildData;

/*---Next core control---*/
TaskHandle_t Task1;

/*------Interrupt detection routine------*/
volatile bool MPUInterrupt = false; // Indicates whether MPU6050 interrupt pin has gone high
void DMPDataReady() { MPUInterrupt = true; }

void initWire();
void initDevice();
void verifyConnection();
void initDMP();
void initWifi();
void calibrate();
int average(int list[]);
float average(float list[]);
void getMode();
float getDirection(float x, float y);
void addToZ(float data);
String toIntensity(float pga);

HTTPClient timer;
void DataControl(void *pvParameters) {
    while (true) {
        if (WiFi.status() != WL_CONNECTED) {
            initWifi();
        }
        if (sendSignal) {
            digitalWrite(LED_BUILTIN, HIGH);
            HTTPClient sender;
            sender.begin(dataServer);
            sender.addHeader("Content-Type", "application/json; charset=UTF-8");
            sender.addHeader("Connection", "keep-alive");
            sendData["id"] = StationID;
            String sendString;
            serializeJson(sendData, sendString);
            int code = sender.POST(sendString);
            if (code == HTTP_CODE_OK) {
                String payload = sender.getString();
                if (payload == "false") { // restart signal from server
                    ESP.restart();
                }
            }
            sender.end();
            // Serial.println(code);
            sendSignal = false;
            // blinkState = !blinkState;
            if (code == 200) {
                digitalWrite(LED_BUILTIN, LOW);
            } else {
                digitalWrite(LED_BUILTIN, HIGH);
            }
        }
        if (discordSignal) {
            discordSignal = false;
            /*
            {
                "content": "⚠️Warning(yyy)⚠️\nEarthquake Detected\n",
                "tts": false,
                "components": [],
                "actions": {},
                "flags": 0,
                "username": "QuakeCord_id",
                "avatar_url": "https://raw.githubusercontent.com/KnowScratcher/QuakeCord/refs/heads/main/src/icon.png"
            }
            */
            String intensity = toIntensity(pga);
            String msg = "{\"content\": \"⚠️Warning(" + intensity +
                         ")⚠️\nEarthquake Detected\n\",\"tts\": false,\"components\": [],\"actions\": {},\"flags\": 0,\"username\": \"QuakeCord\",\"avatar_url\": "
                         "\"https://raw.githubusercontent.com/KnowScratcher/QuakeCord/refs/heads/main/src/icon.png\"}";
            JsonDocument jsn;
            deserializeJson(jsn, msg);
            serializeJson(jsn, msg);
            HTTPClient sender;
            sender.begin(webhook);
            sender.addHeader("Content-Type", "application/json;");
            sender.addHeader("Connection", "keep-alive");
            Serial.println(msg);
            int code = sender.POST(msg);
            Serial.println(code);
        }
        if (reportSignal) {
            reportSignal = false;
            /*
            {
                "content": "⚠️Warning(yyy)⚠️\nEarthquake Detected\n",
                "tts": false,
                "embeds": [
                    {
                        "description": "",
                        "fields": [
                            {
                            "name": "📊 Peak Ground Acceleration (PGA)",
                            "value": "xxx **gal (cm/s^2)**",
                            "inline": true
                            },
                            {
                            "name": "📈 Intensity",
                            "value": "yyy (lol)",
                            "inline": false
                            },
                            {
                            "name": "🧭 Direction",
                            "value": "yyy (lol)",
                            "inline": false
                            }
                        ],
                        "title": "Earthquake Report",
                        "footer": {
                            "text": "report for reference only."
                        },
                        "color": 16711680,
                        "image": {
                            "url": "xxx"
                        }
                    }
                ],

                "components": [],
                "actions": {},
                "flags": 0,
                "username": "QuakeCord",
                "avatar_url": "https://raw.githubusercontent.com/KnowScratcher/QuakeCord/refs/heads/main/src/icon.png"
            }
            */
            String intensity = toIntensity(pga);
            float dir = getDirection(start_x, start_y);
            String msg = "{\"content\": \"⚠️Warning(" + intensity + ")⚠️\nEarthquake Detected\n\",\"tts\": false,\"embeds\": [{\"description\": \"\",\"fields\": [{\"name\": \"📊 Peak Ground Acceleration (PGA)\",\"value\": \"" + pga +
                         " **gal (cm/s^2)**\",\"inline\": true},{\"name\": \"📈 Intensity\",\"value\": \"" + intensity + " (" + mode + ")\",\"inline\": false},{\"name\": \"🧭 Direction (Beta)\",\"value\": \"" + dir + " / " + (dir + 180.0) +
                         "\",\"inline\": false}],\"title\": \"Earthquake Report\",\"footer\": {\"text\": \"report for reference only.\"},\"color\": 16711680}],\"components\": [],\"actions\": {},\"flags\": 0,\"username\": \"QuakeCord\",\"avatar_url\": \"https://raw.githubusercontent.com/KnowScratcher/QuakeCord/refs/heads/main/src/icon.png\"}";
            JsonDocument jsn;
            deserializeJson(jsn, msg);
            serializeJson(jsn, msg);
            HTTPClient sender;
            sender.begin(webhook);
            sender.addHeader("Content-Type", "application/json;");
            sender.addHeader("Connection", "keep-alive");
            Serial.println(msg);
            int code = sender.POST(msg);
            Serial.println(code);
            pga = 0;
        }
        delay(1);
    }
}

void setup() {
    mainCount = 0;
    initWire();
    Serial.begin(115200);
    while (!Serial)
        ;
    initWifi();
    registerTime();
    initDevice();
    verifyConnection();
    initDMP();
    getMode();
    xTaskCreatePinnedToCore(DataControl, /*任務實際對應的Function*/
                            "Task1",     /*任務名稱*/
                            10000,       /*堆疊空間*/
                            NULL,        /*無輸入值*/
                            0,           /*優先序0*/
                            &Task1,      /*對應的任務變數位址*/
                            0);          /*指定在核心0執行 */

    /* Making sure it worked (returns 0 if so) */
    if (devStatus == 0) {
        mpu.CalibrateAccel(50); // Calibration Time: generate offsets and calibrate our MPU6050
        mpu.CalibrateGyro(50);
        // calibrate();
        Serial.println("These are the Active offsets: ");
        mpu.PrintActiveOffsets();
        Serial.println(F("Enabling DMP...")); // Turning ON DMP
        mpu.setDMPEnabled(true);

        /*Enable Arduino interrupt detection*/
        Serial.print(F("Enabling interrupt detection (Arduino external interrupt "));
        Serial.print(digitalPinToInterrupt(INTERRUPT_PIN));
        Serial.println(F(")..."));
        attachInterrupt(digitalPinToInterrupt(INTERRUPT_PIN), DMPDataReady, RISING);
        MPUIntStatus = mpu.getIntStatus();

        /* Set the DMP Ready flag so the main loop() function knows it is okay
         * to use it */
        Serial.println(F("DMP ready! Waiting for first interrupt..."));
        DMPReady = true;
        packetSize = mpu.dmpGetFIFOPacketSize(); // Get expected DMP packet size
                                                 // for later comparison
    } else {
        Serial.print(F("DMP Initialization failed (code ")); // Print the error code
        Serial.print(devStatus);
        Serial.println(F(")"));
        // 1 = initial memory load failed
        // 2 = DMP configuration updates failed
    }
    pinMode(LED_BUILTIN, OUTPUT);
}

void loop() {
    if (!DMPReady)
        return; // Stop the program if DMP programming fails.

    /* Read a packet from FIFO */
    if (mpu.dmpGetCurrentFIFOPacket(FIFOBuffer)) { // Get the Latest packet
        /* Display initial world-frame acceleration, adjusted to remove gravity
        and rotated based on known orientation from Quaternion */
        long nowMill = millis();
        long long dt = nowMill - baseSystemTime;
        dt = (dt > 0) ? dt : dt + 2147483648;
        // Serial.println(dt);

        mpu.dmpGetQuaternion(&q, FIFOBuffer);
        mpu.dmpGetAccel(&aa, FIFOBuffer);
        mpu.dmpGetGravity(&gravity, &q);
        mpu.dmpGetLinearAccel(&aaReal, &aa, &gravity);
        
        float galx = aaReal.x * dataRatio;
        float galy = aaReal.y * dataRatio;
        float galz = aaReal.z * dataRatio;
        
        Serial.print("x:");
        Serial.print(galx);
        Serial.print(",y:");
        Serial.print(galy);
        Serial.print(",z:");
        Serial.print(galz);
        Serial.print(",rx:");
        Serial.print(aaReal.x);
        Serial.print(",ry:");
        Serial.print(aaReal.y);
        Serial.print(",rz:");
        Serial.print(aaReal.z);
        Serial.print(",interest:");
        Serial.print(interest);
        Serial.print(",discord:");
        Serial.println(discordSignal);
        JsonObject appendData = buildData["data"].add<JsonObject>();
        appendData["dt"] = nowMill;
        appendData["x"] = aaReal.x;
        appendData["y"] = aaReal.y;
        appendData["z"] = aaReal.z;
        if (abs(galx) >= threshold || abs(galy) >= threshold || abs(galz) >= threshold) {
            if (interest == 0) {
                start_x = galx;
                start_y = galy;
            }
            interest += 1;
            if (abs(pga - max(pga, max(abs(galx), max(abs(galy), abs(galz))))) > 10) {
                discordLock = false;
            }
            pga = max(pga, max(abs(galx), max(abs(galy), abs(galz))));
        } else if (interest > 0) {
            interest -= 1;
        }
        if (interest > 5 && !discordLock && enableDiscord) {
            discordSignal = true;
            discordLock = true;
        }
        if (interest == 0 && discordLock && enableDiscord) {
            discordLock = false;
            reportSignal = true;
        }

        if (dt > 10000 && enableServer) {
            baseSystemTime = millis();
            if (buildData.size() > 0) {
                sendData = buildData;
                sendSignal = true;
            }
            buildData.clear();
        }
        delay(32);
        errorLevel = 0;
    }else{
        delay(32);
        errorLevel++;
        if (errorLevel > 5) {
            if (mpu.testConnection()) {
                Serial.println("MPU6050 connection re-established.");
                // If connection is good, try to re-enable DMP.
                // This might be redundant if the issue was just a momentary glitch,
                // but good practice if the MPU6050's internal state got corrupted.
                Serial.println("Attempting to re-enable DMP...");
                devStatus = mpu.dmpInitialize();
                if (devStatus == 0) {
                    mpu.CalibrateAccel(50); // Calibration Time: generate offsets and calibrate our MPU6050
                    mpu.CalibrateGyro(50);
                    // calibrate();
                    Serial.println("These are the Active offsets: ");
                    mpu.PrintActiveOffsets();
                    Serial.println(F("Enabling DMP...")); // Turning ON DMP
                    mpu.setDMPEnabled(true);
                    DMPReady = true; // Mark DMP as ready again
                    Serial.println("DMP re-enabled successfully!");
                } else {
                    Serial.print(F("DMP re-initialization failed (code "));
                    Serial.print(devStatus);
                    Serial.println(F("). May need a hard reset."));
                    DMPReady = false; // DMP still not ready
                }
            }else {
                Serial.println("MPU6050 connection still failed. Checking I2C bus...");
                Wire.end();
                initWire();
                if (devStatus == 0) {
                    mpu.CalibrateAccel(50); // Calibration Time: generate offsets and calibrate our MPU6050
                    mpu.CalibrateGyro(50);
                    // calibrate();
                    Serial.println("These are the Active offsets: ");
                    mpu.PrintActiveOffsets();
                    Serial.println(F("Enabling DMP...")); // Turning ON DMP
                    mpu.setDMPEnabled(true);
                    DMPReady = true; // Mark DMP as ready again
                    Serial.println("DMP re-enabled successfully!");
                } else {
                    Serial.print(F("DMP re-initialization failed (code "));
                    Serial.print(devStatus);
                    Serial.println(F("). May need a hard reset."));
                    DMPReady = false; // DMP still not ready
                }
            }
            errorLevel = 0;
        }
    }
}

void initWire() {
#if I2CDEV_IMPLEMENTATION == I2CDEV_ARDUINO_WIRE
    Wire.begin();
    Wire.setClock(400000); // 400kHz I2C clock. Comment on this line if having
                           // compilation difficulties
#elif I2CDEV_IMPLEMENTATION == I2CDEV_BUILTIN_FASTWIRE
    Fastwire::setup(400, true);
#endif
}

void initDevice() {
    /*Initialize device*/
    Serial.println(F("Initializing I2C devices..."));
    mpu.initialize();
    pinMode(INTERRUPT_PIN, INPUT);
}

void verifyConnection() {
    /*Verify connection*/
    Serial.println(F("Testing MPU6050 connection..."));
    if (mpu.testConnection() == false) {
        Serial.println("MPU6050 connection failed");
        while (true)
            ;
    } else {
        Serial.println("MPU6050 connection successful");
    }
}

void initDMP() {
    /* Initializate and configure the DMP*/
    Serial.println(F("Initializing DMP..."));
    devStatus = mpu.dmpInitialize();
}

void initWifi() {
    digitalWrite(LED_BUILTIN, HIGH);
    Serial.println("connecting to wifi");
    WiFi.begin(ssid, password);
    while (WiFi.status() != WL_CONNECTED) {
        Serial.print(".");
        delay(1000);
    }
    Serial.println("Connected");
    Serial.print("IP位址:");
    Serial.println(WiFi.localIP()); //讀取IP位址
    digitalWrite(LED_BUILTIN, LOW);
}

void registerTime() {
    JsonDocument startSignal;
    startSignal["id"] = StationID;
    String ss;
    serializeJson(startSignal, ss);
    timer.begin(registerServer);
    timer.POST(ss);
    timer.end();
}

/*-----Calibrateing-----*/
// void calibrate() {
//     Initialize(); // Initializate and calibrate the sensor
//     for (i = iAx; i <= iGz; i++) {
//         Target[i] = 0; // Fix for ZAccel
//         HighOffset[i] = 0;
//         LowOffset[i] = 0;
//     }
//     Target[iAz] = 0;     // Set the taget for Z axes, original: 16384
//     SetAveraging(NFast); // Fast averaging
//     PullBracketsOut();
//     PullBracketsIn();
//     Serial.println("-------------- DONE --------------");
// }

// /*Initializate function*/
// void Initialize() {
// #if I2CDEV_IMPLEMENTATION == I2CDEV_ARDUINO_WIRE
//     Wire.begin();
// #elif I2CDEV_IMPLEMENTATION == I2CDEV_BUILTIN_FASTWIRE
//     Fastwire::setup(400, true);
// #endif
//     // Check module connection
//     Serial.println("Testing device connections...");
//     if (mpu.testConnection() == false) {
//         Serial.println("MPU6050 connection failed");
//         while (true)
//             ;
//     } else {
//         Serial.println("MPU6050 connection successful");
//     }

//     Serial.println("\nPID tuning Each Dot = 100 readings");
//     /*
//       PID tuning (actually PI) works like this: changing the offset in the
//       MPU6050 gives instant results, allowing us to use the Proportional and
//       Integral parts of the PID to find the ideal offsets. The Integral uses the
//       error from the set point (which is zero) and adds a fraction of this error
//       to the integral value. Each reading reduces the error towards the desired
//       offset. The greater the error, the more we adjust the integral value.

//       The Proportional part helps by filtering out noise from the integral
//       calculation. The Derivative part is not used due to noise and the sensor
//       being stationary. With the noise removed, the integral value stabilizes
//       after about 600 readings. At the end of each set of 100 readings, the
//       integral value is used for the actual offsets, and the last proportional
//       reading is ignored because it reacts to any noise.
//       */
//     Serial.println("\nXAccel\t\tYAccel\t\tZAccel\t\tXGyro\t\tYGyro\t\tZGyro");
//     mpu.CalibrateAccel(6);
//     mpu.CalibrateGyro(6);
//     Serial.println("\n600 Readings");
//     mpu.PrintActiveOffsets();
//     mpu.CalibrateAccel(1);
//     mpu.CalibrateGyro(1);
//     Serial.println("700 Total Readings");
//     mpu.PrintActiveOffsets();
//     mpu.CalibrateAccel(1);
//     mpu.CalibrateGyro(1);
//     Serial.println("800 Total Readings");
//     mpu.PrintActiveOffsets();
//     mpu.CalibrateAccel(1);
//     mpu.CalibrateGyro(1);
//     Serial.println("900 Total Readings");
//     mpu.PrintActiveOffsets();
//     mpu.CalibrateAccel(1);
//     mpu.CalibrateGyro(1);
//     Serial.println("1000 Total Readings");
//     mpu.PrintActiveOffsets();
//     Serial.println("\nAny of the above offsets will work nicely \n\nProving "
//                    "the PID with other method:");
// }

void SetAveraging(int NewN) {
    N = NewN;
    Serial.print("\nAveraging ");
    Serial.print(N);
    Serial.println(" readings each time");
}
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

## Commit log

2025-05-25 update bom
2025-05-31 change file storage paths
    [BOM.csv, QuakeCord.FCStd, QuakeCord_Design.dxf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]
2025-05-31 change file structure
    [QuakeCord_case-cap.3mf, QuakeCord_case-case.3mf, QuakeCord_case.3mf]
2025-05-31 add step file
    [QuakeCord_case-cap.step, QuakeCord_case-case.step, QuakeCord_case.step]
2025-05-31 update model
    [QuakeCord.FCStd, QuakeCord_case-cap.3mf, QuakeCord_case-cap.step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]
2025-05-31 update to new model
    [QuakeCord.FCStd, QuakeCord_case-cap.3mf, QuakeCord_case-cap.step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]
2025-06-02 update model and add stl support
    [QuakeCord_case-cap.3mf, QuakeCord_case-cap.step, QuakeCord_case-cap.stl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]
2025-06-02 update model and README and journal
    [QuakeCord_case-cap.3mf, QuakeCord_case-cap.step, QuakeCord_case-cap.stl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]
2025-06-08 add journal
    [QuakeCord_case-cap.3mf, QuakeCord_case-cap.step, QuakeCord_case-cap.stl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]
2025-06-08 add firmware
    [freefall_experiment.xlsx]
2025-06-08 fix BOM
2025-06-10 update model and update stl
    [QuakeCord_case-cap.stl, QuakeCord_case.FCStd, QuakeCord_case.stl]
2025-06-19 update journal
    [QuakeCord_case.FCStd]
2025-06-21 update firmware
    [QuakeCord_case.FCStd]
